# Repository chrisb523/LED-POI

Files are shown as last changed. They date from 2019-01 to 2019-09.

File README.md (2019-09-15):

# LED POI Project
This is a project that converts JPEG format images to code usable on LED poi with arduino-based operating systems. Additionally, it contains the documentation necessescary to build poi, in addition to the materials I used to build them myself. Furthermore, it outlines some of the difficulties I had along the way developing both the software and hardware components, and the solutions I found. The project is still in development, but most features are reliable and tested. I would encourage modification of the original programs and hardware to any specifications.   

# Running and Compiling the Program:

First begin by placing the desired image, which must be in the JPEG format (.jpg) into the arduino program directory (/makerpoi_code/)

Then, ensure that the number of pixels is correctly defined in convert.py (only nessescary if you change the number of LEDs)
Before running the program, see the software section, and ensure you have all of the dependencies

Execute the run.bat file in the program directory, or use a shell to execute the convert.py program

Examine the arduino code file, and ensure that are variables are set correctly to the specifications of the project 
  -Make sure the Pinout is correct
  -Make sure the voltages in the battery measuring function are correct (depending on whether you are using 3.3v or 5v logic)
  
# Software: 
The project is based off of python 3.7 and C++ (Which is used by arduino IDE). The download link to python 3.7 is (https://www.python.org/downloads/release/python-373/) and the download link to arduino IDE is (https://www.arduino.cc/en/main/software). For the python install, remember to set environment variables. In addition to python, one must also install or upgrade pip, which can be done from the command line using: 

py -m pip upgrade pip

Then, install all dependencies for the convert image program (cv2, PIL, and numpy). However, PIL has been deprecated, and PILLOW is in use with more recent versions of python. To install it, use:

 py -m pip install pillow
 
This should meet all of the basic installation requirements for the project. However, there are some aspects of the ardino IDE that may need to be tweaked. The SAMD boards for arduino have to be installed, in addition to the Neopixel library. With this, all of the software should be configured correctly.

Then, install the Trinket m0 board using this link: https://adafruit.github.io/arduino-board-index/package_adafruit_index.json

 # Hardware: 
The project requires a number of hardware components, most of which are . All of the hardware can be purchased from Adafruit's website or Amazon. For the project, I used the following parts: 

ALITOVE 3.2ft 144 Pixels WS2812B Individually Addressable LED Strip Light (https://www.amazon.com/gp/product/B019DYZNO6/ref=ppx_yo_dt_b_asin_title_o07_s00?ie=UTF8&psc=1)

2 of Adafruit Trinket M0 - for use with CircuitPython & Arduino IDE (https://www.amazon.com/gp/product/B01MR2S7K0/ref=ppx_yo_dt_b_asin_title_o00_s00?ie=UTF8&psc=1)

Breadboard and generic wires (Avaliable from numerous electronic stores)

Micro-USB cable (https://www.amazon.com/AmazonBasics-Male-Micro-Cable-Black/dp/B072J1BSV6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)

2 of uxcell Power Supply DC 3.7V 500mAh Li-po batteries (https://www.amazon.com/gp/product/B0767D8GVG/ref=ppx_yo_dt_b_asin_title_o00_s00?ie=UTF8&psc=1)

2 of Adafruit LiIon/LiPoly Backpack Add-On for Pro Trinket/ItsyBitsy (https://www.adafruit.com/product/2124)

Generic Nylon Rope

In total, the project cost me around $66.00, as I had a breadboard, wires, nylon cord, and cables. 
-------------------------------------------------------------------------------------------------------
Additional Items:
If you so wish to build the cases for the POI, it will cost extra, but I found that it was important to build them to protect from water damage and collisions. 

4 Vinyl Caps
(https://www.amazon.com/gp/product/B0747RVMRZ/ref=ppx_yo_dt_b_asin_title_o04_s00?ie=UTF8&psc=1)

Clear Polycarbonate Tubing, 1-1/8" ID, 1-1/4" OD, 1/16" Wall, 3' Length
(https://www.amazon.com/gp/product/B000OMFLD0/ref=ppx_yo_dt_b_asin_title_o05_s00?ie=UTF8&psc=1)

Tissue Paper or Towels - To act as a shock absorber and spacer

# Assembly

The initial development board appeared as so, with some soldering required for the test board:

# Software Development

The software development began with the convert.py script developed in python. It converts the image to an rgb array, and prints it out in the format of a header file. This process was not easy, and the file was cleaned by multiple replace functions. It can be run with the run.bat file. 

Initially, I had written the python script to export a header file that contained all of the rgb values in arrays. However, I later decided to make the python script handle the placements of these values directly into the files. This reduced the time taken by the trinket board to process the images, and allowed for a clearer image with higher resolution. 

With the second version of the project, I added a battery detector to tell the user whether or not the battery is running low, using the colors red and green. This was enabled by the soldering of the usb pin to an analog read pin, and a software analog read function that detetected the voltage on startup. Futhermore, this feature also has the ability to prevent the POI from displaying the image at all if the POI are charging or plugged into a computer for code upload. Instead, the POI will flash blue one time. This works due to the property that the USB pin outputs differing voltages based on factors such as battery level, and whether or not the POI are charging.

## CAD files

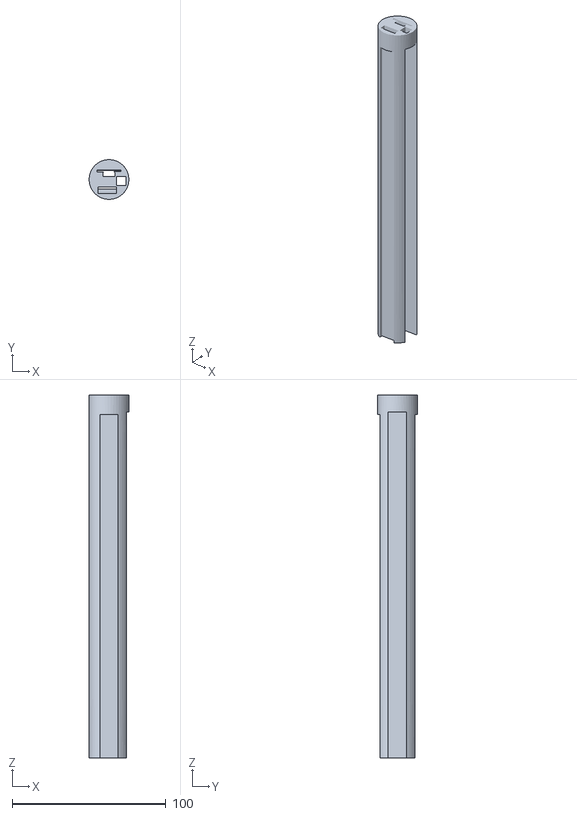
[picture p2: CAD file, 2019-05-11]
poiinsert.stl
25.9 x 25.8 x 236.2

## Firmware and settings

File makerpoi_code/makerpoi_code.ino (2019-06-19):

#define VBATPIN 2
#include <Adafruit_NeoPixel.h>
#define PIN 1
#define NUM_LEDS 32
#define Button 3
Adafruit_NeoPixel strip = Adafruit_NeoPixel(32, PIN, NEO_GRB + NEO_KHZ800);
float measuredvbat;
int buttonState = 0;
int img = 1;
int numimg = 2;
void setup() {
  strip.begin();
  strip.setBrightness(40);
  measuredvbat = bat();
  for (int i = 0; i < 32; i++) {
    if (measuredvbat > 1.5 && measuredvbat < 2)
      strip.setPixelColor(i, 0, 255, 0);
    if (measuredvbat > 3.29 && measuredvbat < 3.31)
      strip.setPixelColor(i, 0, 0, 255);
    if (measuredvbat < 1.5)
      strip.setPixelColor(i, 255, 0, 0);
  }
  strip.show();
  delay(500);
  strip.clear();
  strip.show();
  pinMode(Button, INPUT);
}
float bat() {
  float measuredvbat = analogRead(VBATPIN);
  return measuredvbat * 3.30 / 1023;
}
void loop() {
  while (measuredvbat > 3.29) {
    delay(1);
  }
  buttonState = digitalRead(Button);
  if (buttonState == HIGH) {
    img++;
    delay(32);
  }
  if (img > numimg)
    img = 1;

  if (img == 1)
    image0();
  if (img == 2)
    image1();
}
void image0() {
  strip.setPixelColor(0, 0, 125, 100);
  strip.setPixelColor(1, 57, 175, 163);
  strip.setPixelColor(2, 108, 209, 221);
  strip.setPixelColor(3, 128, 206, 245);
  strip.setPixelColor(4, 134, 198, 255);
  strip.setPixelColor(5, 129, 201, 255);
  strip.setPixelColor(6, 102, 210, 255);
  strip.setPixelColor(7, 67, 220, 255);
  strip.setPixelColor(8, 40, 222, 236);
  strip.setPixelColor(9, 21, 185, 187);
  strip.setPixelColor(10, 0, 99, 102);
  strip.setPixelColor(11, 0, 12, 22);
  strip.setPixelColor(12, 6, 0, 9);
  strip.setPixelColor(13, 12, 3, 8);
  strip.setPixelColor(14, 0, 18, 7);
  strip.setPixelColor(15, 0, 20, 0);
  strip.setPixelColor(16, 22, 0, 0);
  strip.setPixelColor(17, 7, 0, 18);
  strip.setPixelColor(18, 0, 1, 28);
  strip.setPixelColor(19, 0, 10, 0);
  strip.setPixelColor(20, 10, 1, 0);
  strip.setPixelColor(21, 75, 14, 29);
  strip.setPixelColor(22, 203, 89, 140);
  strip.setPixelColor(23, 255, 146, 124);
  strip.setPixelColor(24, 255, 184, 15);
  strip.setPixelColor(25, 255, 201, 0);
  strip.setPixelColor(26, 237, 213, 0);
  strip.setPixelColor(27, 219, 215, 2);
  strip.setPixelColor(28, 229, 219, 36);
  strip.setPixelColor(29, 251, 205, 67);
  strip.setPixelColor(30, 239, 142, 100);
  strip.setPixelColor(31, 255, 121, 176);
  strip.show();
  delay(1);
  strip.setPixelColor(0, 0, 49, 34);
  strip.setPixelColor(1, 15, 107, 102);
  strip.setPixelColor(2, 76, 169, 177);
  strip.setPixelColor(3, 109, 200, 229);
  strip.setPixelColor(4, 115, 206, 251);
  strip.setPixelColor(5, 106, 201, 255);
  strip.setPixelColor(6, 97, 206, 255);
  strip.setPixelColor(7, 96, 223, 255);
  strip.setPixelColor(8, 81, 221, 248);
  strip.setPixelColor(9, 73, 205, 218);
  strip.setPixelColor(10, 51, 156, 160);
  strip.setPixelColor(11, 14, 84, 86);
  strip.setPixelColor(12, 0, 22, 23);
  strip.setPixelColor(13, 0, 6, 5);
  strip.setPixelColor(14, 0, 6, 0);
  strip.setPixelColor(15, 0, 16, 6);
  strip.setPixelColor(16, 17, 0, 2);
  strip.setPixelColor(17, 19, 8, 6);
  strip.setPixelColor(18, 2, 4, 3);
  strip.setPixelColor(19, 5, 0, 16);
  strip.setPixelColor(20, 37, 2, 24);
  strip.setPixelColor(21, 175, 106, 90);
  strip.setPixelColor(22, 255, 169, 90);
  strip.setPixelColor(23, 255, 174, 51);
  strip.setPixelColor(24, 255, 194, 42);
  strip.setPixelColor(25, 255, 198, 6);
  strip.setPixelColor(26, 240, 203, 0);
  strip.setPixelColor(27, 248, 212, 0);
  strip.setPixelColor(28, 253, 205, 35);
  strip.setPixelColor(29, 234, 166, 93);
  strip.setPixelColor(30, 224, 146, 142);
  strip.setPixelColor(31, 98, 18, 43);
  strip.show();
  delay(1);
  strip.setPixelColor(0, 0, 13, 11);
  strip.setPixelColor(1, 0, 34, 33);
  strip.setPixelColor(2, 20, 97, 103);
  strip.setPixelColor(3, 64, 166, 180);
  strip.setPixelColor(4, 91, 210, 232);
  strip.setPixelColor(5, 91, 214, 247);
  strip.setPixelColor(6, 96, 207, 250);
  strip.setPixelColor(7, 114, 209, 255);
  strip.setPixelColor(8, 124, 208, 252);
  strip.setPixelColor(9, 122, 211, 241);
  strip.setPixelColor(10, 101, 205, 216);
  strip.setPixelColor(11, 54, 167, 163);
  strip.setPixelColor(12, 0, 94, 82);
  strip.setPixelColor(13, 0, 24, 16);
  strip.setPixelColor(14, 0, 5, 5);
  strip.setPixelColor(15, 17, 0, 8);
  strip.setPixelColor(16, 11, 0, 21);
  strip.setPixelColor(17, 8, 0, 0);
  strip.setPixelColor(18, 10, 0, 0);
  strip.setPixelColor(19, 37, 2, 32);
  strip.setPixelColor(20, 185, 121, 156);
  strip.setPixelColor(21, 245, 172, 104);
  strip.setPixelColor(22, 255, 202, 12);
  strip.setPixelColor(23, 255, 205, 0);
  strip.setPixelColor(24, 251, 201, 28);
  strip.setPixelColor(25, 245, 190, 35);
  strip.setPixelColor(26, 255, 202, 6);
  strip.setPixelColor(27, 255, 195, 0);
  strip.setPixelColor(28, 251, 155, 42);
  strip.setPixelColor(29, 231, 146, 141);
  strip.setPixelColor(30, 76, 32, 57);
  strip.setPixelColor(31, 4, 0, 0);
  strip.show();
  delay(1);
  strip.setPixelColor(0, 0, 2, 5);
  strip.setPixelColor(1, 0, 6, 11);
  strip.setPixelColor(2, 0, 27, 30);
  strip.setPixelColor(3, 9, 99, 100);
  strip.setPixelColor(4, 58, 182, 184);
  strip.setPixelColor(5, 86, 220, 229);
  strip.setPixelColor(6, 98, 214, 239);
  strip.setPixelColor(7, 118, 197, 238);
  strip.setPixelColor(8, 140, 193, 243);
  strip.setPixelColor(9, 136, 198, 239);
  strip.setPixelColor(10, 114, 210, 232);
  strip.setPixelColor(11, 78, 212, 211);
  strip.setPixelColor(12, 36, 172, 158);
  strip.setPixelColor(13, 4, 97, 87);
  strip.setPixelColor(14, 0, 21, 26);
  strip.setPixelColor(15, 15, 0, 9);
  strip.setPixelColor(16, 1, 0, 26);
  strip.setPixelColor(17, 11, 0, 8);
  strip.setPixelColor(18, 46, 15, 10);
  strip.setPixelColor(19, 180, 124, 107);
  strip.setPixelColor(20, 240, 168, 118);
  strip.setPixelColor(21, 255, 198, 81);
  strip.setPixelColor(22, 232, 182, 0);
  strip.setPixelColor(23, 249, 216, 0);
  strip.setPixelColor(24, 237, 204, 0);
  strip.setPixelColor(25, 255, 202, 1);
  strip.setPixelColor(26, 255, 193, 41);
  strip.setPixelColor(27, 255, 155, 67);
  strip.setPixelColor(28, 241, 130, 110);
  strip.setPixelColor(29, 88, 15, 34);
  strip.setPixelColor(30, 17, 3, 20);
  strip.setPixelColor(31, 0, 12, 8);
  strip.show();
  delay(1);
  strip.setPixelColor(0, 16, 11, 17);
  strip.setPixelColor(1, 0, 0, 5);
  strip.setPixelColor(2, 0, 7, 9);
  strip.setPixelColor(3, 0, 32, 29);
  strip.setPixelColor(4, 13, 108, 100);
  strip.setPixelColor(5, 57, 176, 172);
  strip.setPixelColor(6, 93, 208, 215);
  strip.setPixelColor(7, 121, 211, 237);
  strip.setPixelColor(8, 131, 198, 240);
  strip.setPixelColor(9, 129, 196, 239);
  strip.setPixelColor(10, 113, 203, 237);
  strip.setPixelColor(11, 93, 215, 230);
  strip.setPixelColor(12, 85, 215, 217);
  strip.setPixelColor(13, 68, 171, 170);
  strip.setPixelColor(14, 32, 82, 91);
  strip.setPixelColor(15, 0, 6, 22);
  strip.setPixelColor(16, 0, 16, 24);
  strip.setPixelColor(17, 1, 0, 28);
  strip.setPixelColor(18, 157, 106, 123);
  strip.setPixelColor(19, 252, 182, 113);
  strip.setPixelColor(20, 255, 190, 41);
  strip.setPixelColor(21, 221, 169, 5);
  strip.setPixelColor(22, 255, 221, 58);
  strip.setPixelColor(23, 238, 200, 0);
  strip.setPixelColor(24, 255, 213, 0);
  strip.setPixelColor(25, 255, 202, 0);
  strip.setPixelColor(26, 255, 156, 58);
  strip.setPixelColor(27, 238, 137, 151);
  strip.setPixelColor(28, 89, 18, 52);
  strip.setPixelColor(29, 21, 0, 0);
  strip.setPixelColor(30, 2, 1, 0);
  strip.setPixelColor(31, 3, 10, 38);
  strip.show();
  delay(1);
  strip.setPixelColor(0, 0, 0, 2);
  strip.setPixelColor(1, 5, 3, 4);
  strip.setPixelColor(2, 0, 0, 2);
  strip.setPixelColor(3, 0, 5, 4);
  strip.setPixelColor(4, 0, 28, 23);
  strip.setPixelColor(5, 14, 91, 83);
  strip.setPixelColor(6, 62, 165, 162);
  strip.setPixelColor(7, 108, 219, 228);
  strip.setPixelColor(8, 106, 212, 236);
  strip.setPixelColor(9, 116, 214, 251);
  strip.setPixelColor(10, 115, 208, 249);
  strip.setPixelColor(11, 110, 204, 240);
  strip.setPixelColor(12, 119, 213, 241);
  strip.setPixelColor(13, 115, 206, 225);
  strip.setPixelColor(14, 69, 153, 164);
  strip.setPixelColor(15, 13, 90, 98);
  strip.setPixelColor(16, 0, 25, 21);
  strip.setPixelColor(17, 0, 1, 25);
  strip.setPixelColor(18, 85, 36, 42);
  strip.setPixelColor(19, 240, 164, 86);
  strip.setPixelColor(20, 255, 201, 35);
  strip.setPixelColor(21, 255, 219, 27);
  strip.setPixelColor(22, 231, 200, 22);
  strip.setPixelColor(23, 255, 206, 29);
  strip.setPixelColor(24, 255, 205, 25);
  strip.setPixelColor(25, 255, 155, 19);
  strip.setPixelColor(26, 232, 141, 97);
  strip.setPixelColor(27, 75, 26, 47);
  strip.setPixelColor(28, 4, 0, 14);
  strip.setPixelColor(29, 0, 9, 0);
  strip.setPixelColor(30, 9, 0, 7);
  strip.setPixelColor(31, 22, 0, 34);
  strip.show();
  delay(1);
  strip.setPixelColor(0, 0, 2, 2);
  strip.setPixelColor(1, 1, 1, 1);
  strip.setPixelColor(2, 10, 2, 0);
  strip.setPixelColor(3, 8, 0, 0);
  strip.setPixelColor(4, 0, 0, 0);
  strip.setPixelColor(5, 0, 20, 15);
  strip.setPixelColor(6, 18, 93, 88);
  strip.setPixelColor(7, 50, 169, 167);
  strip.setPixelColor(8, 70, 211, 220);
  strip.setPixelColor(9, 88, 222, 247);
  strip.setPixelColor(10, 108, 215, 255);
  strip.setPixelColor(11, 122, 198, 250);
  strip.setPixelColor(12, 133, 196, 247);
  strip.setPixelColor(13, 129, 207, 245);
  strip.setPixelColor(14, 89, 199, 216);
  strip.setPixelColor(15, 44, 178, 181);
  strip.setPixelColor(16, 0, 90, 96);
  strip.setPixelColor(17, 0, 26, 11);
  strip.setPixelColor(18, 15, 0, 0);
  strip.setPixelColor(19, 100, 40, 0);
  strip.setPixelColor(20, 242, 180, 67);
  strip.setPixelColor(21, 247, 207, 31);
  strip.setPixelColor(22, 234, 199, 0);
  strip.setPixelColor(23, 255, 196, 45);
  strip.setPixelColor(24, 242, 141, 85);
  strip.setPixelColor(25, 232, 127, 131);
  strip.setPixelColor(26, 81, 20, 15);
  strip.setPixelColor(27, 4, 10, 0);
  strip.setPixelColor(28, 0, 17, 0);
  strip.setPixelColor(29, 0, 12, 13);
  strip.setPixelColor(30, 18, 0, 26);
  strip.setPixelColor(31, 41, 0, 18);
  strip.show();
  delay(1);
  strip.setPixelColor(0, 6, 5, 10);
  strip.setPixelColor(1, 0, 0, 0);
  strip.setPixelColor(2, 4, 0, 0);
  strip.setPixelColor(3, 16, 2, 0);
  strip.setPixelColor(4, 14, 0, 0);
  strip.setPixelColor(5, 1, 0, 0);
  strip.setPixelColor(6, 0, 30, 30);
  strip.setPixelColor(7, 0, 95, 94);
  strip.setPixelColor(8, 50, 194, 195);
  strip.setPixelColor(9, 59, 215, 230);
  strip.setPixelColor(10, 89, 217, 252);
  strip.setPixelColor(11, 114, 199, 254);
  strip.setPixelColor(12, 129, 191, 252);
  strip.setPixelColor(13, 124, 200, 249);
  strip.setPixelColor(14, 98, 213, 242);
  strip.setPixelColor(15, 68, 218, 232);
  strip.setPixelColor(16, 55, 170, 201);
  strip.setPixelColor(17, 18, 104, 77);
  strip.setPixelColor(18, 0, 27, 0);
  strip.setPixelColor(19, 20, 3, 0);
  strip.setPixelColor(20, 82, 32, 0);
  strip.setPixelColor(21, 221, 164, 48);
  strip.setPixelColor(22, 255, 220, 77);
  strip.setPixelColor(23, 235, 167, 82);
  strip.setPixelColor(24, 211, 132, 151);
  strip.setPixelColor(25, 81, 18, 73);
  strip.setPixelColor(26, 15, 0, 0);
  strip.setPixelColor(27, 0, 13, 0);
  strip.setPixelColor(28, 0, 16, 0);
  strip.setPixelColor(29, 0, 0, 19);
  strip.setPixelColor(30, 13, 0, 18);
  strip.setPixelColor(31, 37, 0, 0);
  strip.show();
  delay(1);
  strip.setPixelColor(0, 7, 0, 5);
  strip.setPixelColor(1, 4, 2, 5);
  strip.setPixelColor(2, 5, 7, 4);
  strip.setPixelColor(3, 3, 0, 0);
  strip.setPixelColor(4, 11, 0, 0);
  strip.setPixelColor(5, 11, 0, 0);
  strip.setPixelColor(6, 0, 4, 10);
  strip.setPixelColor(7, 0, 17, 21);
  strip.setPixelColor(8, 0, 98, 102);
  strip.setPixelColor(9, 44, 188, 199);
  strip.setPixelColor(10, 73, 217, 241);
  strip.setPixelColor(11, 97, 215, 255);
  strip.setPixelColor(12, 116, 210, 255);
  strip.setPixelColor(13, 100, 192, 243);
  strip.setPixelColor(14, 107, 216, 255);
  strip.setPixelColor(15, 91, 215, 249);
  strip.setPixelColor(16, 90, 202, 248);
  strip.setPixelColor(17, 58, 168, 167);
  strip.setPixelColor(18, 15, 104, 48);
  strip.setPixelColor(19, 0, 32, 0);
  strip.setPixelColor(20, 18, 4, 0);
  strip.setPixelColor(21, 108, 43, 1);
  strip.setPixelColor(22, 216, 133, 119);
  strip.setPixelColor(23, 206, 139, 146);
  strip.setPixelColor(24, 50, 20, 32);
  strip.setPixelColor(25, 7, 10, 15);
  strip.setPixelColor(26, 0, 5, 5);
  strip.setPixelColor(27, 3, 4, 9);
  strip.setPixelColor(28, 9, 0, 12);
  strip.setPixelColor(29, 11, 0, 9);
  strip.setPixelColor(30, 8, 0, 0);
  strip.setPixelColor(31, 4, 8, 0);
  strip.show();
  delay(1);
  strip.setPixelColor(0, 7, 0, 5);
  strip.setPixelColor(1, 1, 0, 4);
  strip.setPixelColor(2, 0, 1, 0);
  strip.setPixelColor(3, 0, 4, 0);
  strip.setPixelColor(4, 8, 3, 0);
  strip.setPixelColor(5, 16, 1, 4);
  strip.setPixelColor(6, 13, 3, 12);
  strip.setPixelColor(7, 0, 10, 19);
  strip.setPixelColor(8, 0, 26, 35);
  strip.setPixelColor(9, 0, 91, 98);
  strip.setPixelColor(10, 23, 161, 172);
  strip.setPixelColor(11, 73, 218, 237);
  strip.setPixelColor(12, 83, 216, 247);
  strip.setPixelColor(13, 113, 226, 255);
  strip.setPixelColor(14, 106, 202, 253);
  strip.setPixelColor(15, 112, 197, 252);
  strip.setPixelColor(16, 110, 209, 248);
  strip.setPixelColor(17, 93, 207, 241);
  strip.setPixelColor(18, 48, 172, 170);
  strip.setPixelColor(19, 9, 112, 59);
  strip.setPixelColor(20, 0, 29, 0);
  strip.setPixelColor(21, 25, 0, 0);
  strip.setPixelColor(22, 80, 6, 69);
  strip.setPixelColor(23, 75, 27, 75);
  strip.setPixelColor(24, 7, 15, 2);
  strip.setPixelColor(25, 0, 17, 0);
  strip.setPixelColor(26, 0, 7, 14);
  strip.setPixelColor(27, 8, 0, 43);
  strip.setPixelColor(28, 30, 0, 26);
  strip.setPixelColor(29, 26, 0, 0);
  strip.setPixelColor(30, 0, 8, 0);
  strip.setPixelColor(31, 0, 16, 0);
  strip.show();
  delay(1);
  strip.setPixelColor(0, 2, 5, 10);
  strip.setPixelColor(1, 0, 0, 4);
  strip.setPixelColor(2, 1, 0, 4);
  strip.setPixelColor(3, 3, 0, 2);
  strip.setPixelColor(4, 4, 0, 2);
  strip.setPixelColor(5, 6, 0, 2);
  strip.setPixelColor(6, 6, 0, 4);
  strip.setPixelColor(7, 2, 1, 9);
  strip.setPixelColor(8, 0, 9, 15);
  strip.setPixelColor(9, 0, 18, 19);
  strip.setPixelColor(10, 9, 118, 115);
  strip.setPixelColor(11, 21, 165, 165);
  strip.setPixelColor(12, 72, 223, 234);
  strip.setPixelColor(13, 98, 223, 255);
  strip.setPixelColor(14, 119, 204, 255);
  strip.setPixelColor(15, 129, 186, 255);
  strip.setPixelColor(16, 117, 196, 227);
  strip.setPixelColor(17, 107, 213, 255);
  strip.setPixelColor(18, 67, 203, 251);
  strip.setPixelColor(19, 38, 174, 196);
  strip.setPixelColor(20, 6, 100, 102);
  strip.setPixelColor(21, 0, 9, 21);
  strip.setPixelColor(22, 8, 0, 21);
  strip.setPixelColor(23, 16, 0, 20);
  strip.setPixelColor(24, 0, 7, 3);
  strip.setPixelColor(25, 0, 9, 4);
  strip.setPixelColor(26, 0, 2, 25);
  strip.setPixelColor(27, 8, 0, 32);
  strip.setPixelColor(28, 24, 0, 11);
  strip.setPixelColor(29, 20, 0, 0);
  strip.setPixelColor(30, 0, 9, 0);
  strip.setPixelColor(31, 0, 14, 5);
  strip.show();
  delay(1);
  strip.setPixelColor(0, 0, 11, 2);
  strip.setPixelColor(1, 0, 6, 5);
  strip.setPixelColor(2, 10, 0, 7);
  strip.setPixelColor(3, 14, 0, 7);
  strip.setPixelColor(4, 10, 0, 7);
  strip.setPixelColor(5, 1, 0, 5);
  strip.setPixelColor(6, 0, 1, 0);
  strip.setPixelColor(7, 8, 4, 1);
  strip.setPixelColor(8, 6, 1, 0);
  strip.setPixelColor(9, 0, 6, 0);
  strip.setPixelColor(10, 0, 34, 19);
  strip.setPixelColor(11, 11, 118, 102);
  strip.setPixelColor(12, 27, 158, 153);
  strip.setPixelColor(13, 100, 221, 240);
  strip.setPixelColor(14, 106, 192, 239);
  strip.setPixelColor(15, 139, 196, 255);
  strip.setPixelColor(16, 140, 201, 246);
  strip.setPixelColor(17, 118, 210, 255);
  strip.setPixelColor(18, 78, 208, 255);
  strip.setPixelColor(19, 62, 213, 255);
  strip.setPixelColor(20, 38, 174, 232);
  strip.setPixelColor(21, 0, 95, 110);
  strip.setPixelColor(22, 0, 39, 14);
  strip.setPixelColor(23, 0, 8, 0);
  strip.setPixelColor(24, 6, 3, 14);
  strip.setPixelColor(25, 7, 0, 32);
  strip.setPixelColor(26, 4, 0, 25);
  strip.setPixelColor(27, 0, 1, 6);
  strip.setPixelColor(28, 0, 1, 0);
  strip.setPixelColor(29, 0, 0, 5);
  strip.setPixelColor(30, 0, 6, 11);
  strip.setPixelColor(31, 0, 5, 2);
  strip.show();
  delay(1);
  strip.setPixelColor(0, 0, 12, 0);
  strip.setPixelColor(1, 0, 9, 3);
  strip.setPixelColor(2, 14, 0, 8);
  strip.setPixelColor(3, 18, 0, 9);
  strip.setPixelColor(4, 17, 0, 17);
  strip.setPixelColor(5, 10, 9, 17);
  strip.setPixelColor(6, 3, 8, 2);
  strip.setPixelColor(7, 9, 3, 0);
  strip.setPixelColor(8, 17, 0, 0);
  strip.setPixelColor(9, 23, 2, 0);
  strip.setPixelColor(10, 0, 5, 0);
  strip.setPixelColor(11, 0, 17, 0);
  strip.setPixelColor(12, 28, 112, 97);
  strip.setPixelColor(13, 48, 146, 155);
  strip.setPixelColor(14, 108, 201, 235);
  strip.setPixelColor(15, 122, 203, 255);
  strip.setPixelColor(16, 138, 198, 255);
  strip.setPixelColor(17, 115, 198, 252);
  strip.setPixelColor(18, 91, 207, 255);
  strip.setPixelColor(19, 88, 232, 255);
  strip.setPixelColor(20, 63, 222, 255);
  strip.setPixelColor(21, 28, 177, 199);
  strip.setPixelColor(22, 1, 110, 91);
  strip.setPixelColor(23, 0, 18, 0);
  strip.setPixelColor(24, 1, 0, 2);
  strip.setPixelColor(25, 15, 0, 7);
  strip.setPixelColor(26, 10, 0, 3);
  strip.setPixelColor(27, 0, 7, 2);
  strip.setPixelColor(28, 0, 8, 16);
  strip.setPixelColor(29, 0, 4, 27);
  strip.setPixelColor(30, 0, 2, 14);
  strip.setPixelColor(31, 8, 0, 0);
  strip.show();
  delay(1);
  strip.setPixelColor(0, 0, 7, 0);
  strip.setPixelColor(1, 2, 8, 0);
  strip.setPixelColor(2, 4, 0, 4);
  strip.setPixelColor(3, 7, 0, 11);
  strip.setPixelColor(4, 12, 3, 22);
  strip.setPixelColor(5, 8, 5, 14);
  strip.setPixelColor(6, 4, 0, 0);
  strip.setPixelColor(7, 15, 0, 0);
  strip.setPixelColor(8, 79, 44, 6);
  strip.setPixelColor(9, 131, 84, 40);
  strip.setPixelColor(10, 40, 2, 0);
  strip.setPixelColor(11, 11, 1, 0);
  strip.setPixelColor(12, 0, 12, 0);
  strip.setPixelColor(13, 20, 88, 89);
  strip.setPixelColor(14, 58, 154, 176);
  strip.setPixelColor(15, 96, 206, 239);
  strip.setPixelColor(16, 114, 192, 255);
  strip.setPixelColor(17, 112, 197, 252);
  strip.setPixelColor(18, 106, 204, 239);
  strip.setPixelColor(19, 99, 223, 247);
  strip.setPixelColor(20, 78, 227, 251);
  strip.setPixelColor(21, 65, 219, 245);
  strip.setPixelColor(22, 51, 184, 203);
  strip.setPixelColor(23, 16, 100, 102);
  strip.setPixelColor(24, 0, 18, 2);
  strip.setPixelColor(25, 4, 2, 0);
  strip.setPixelColor(26, 6, 0, 0);
  strip.setPixelColor(27, 0, 3, 10);
  strip.setPixelColor(28, 0, 6, 28);
  strip.setPixelColor(29, 0, 4, 25);
  strip.setPixelColor(30, 0, 1, 5);
  strip.setPixelColor(31, 7, 0, 0);
  strip.show();
  delay(1);
  strip.setPixelColor(0, 17, 0, 0);
  strip.setPixelColor(1, 10, 3, 0);
  strip.setPixelColor(2, 0, 3, 2);
  strip.setPixelColor(3, 0, 4, 12);
  strip.setPixelColor(4, 0, 2, 16);
  strip.setPixelColor(5, 1, 0, 7);
  strip.setPixelColor(6, 22, 0, 0);
  strip.setPixelColor(7, 75, 35, 9);
  strip.setPixelColor(8, 192, 138, 91);
  strip.setPixelColor(9, 222, 158, 97);
  strip.setPixelColor(10, 177, 113, 52);
  strip.setPixelColor(11, 62, 11, 0);
  strip.setPixelColor(12, 13, 0, 0);
  strip.setPixelColor(13, 0, 15, 11);
  strip.setPixelColor(14, 1, 99, 110);
  strip.setPixelColor(15, 26, 161, 180);
  strip.setPixelColor(16, 88, 197, 240);
  strip.setPixelColor(17, 119, 216, 255);
  strip.setPixelColor(18, 122, 208, 241);
  strip.setPixelColor(19, 111, 204, 219);
  strip.setPixelColor(20, 98, 211, 219);
  strip.setPixelColor(21, 87, 221, 233);
  strip.setPixelColor(22, 77, 216, 237);
  strip.setPixelColor(23, 58, 179, 190);
  strip.setPixelColor(24, 12, 93, 84);
  strip.setPixelColor(25, 2, 41, 22);
  strip.setPixelColor(26, 0, 3, 0);
  strip.setPixelColor(27, 6, 0, 0);
  strip.setPixelColor(28, 6, 1, 5);
  strip.setPixelColor(29, 0, 2, 1);
  strip.setPixelColor(30, 0, 4, 4);
  strip.setPixelColor(31, 0, 3, 11);
  strip.show();
  delay(1);
  strip.setPixelColor(0, 32, 0, 0);
  strip.setPixelColor(1, 11, 0, 0);
  strip.setPixelColor(2, 0, 9, 1);
  strip.setPixelColor(3, 0, 21, 20);
  strip.setPixelColor(4, 0, 10, 18);
  strip.setPixelColor(5, 1, 0, 7);
  strip.setPixelColor(6, 81, 43, 42);
  strip.setPixelColor(7, 194, 136, 112);
  strip.setPixelColor(8, 235, 168, 116);
  strip.setPixelColor(9, 255, 194, 125);
  strip.setPixelColor(10, 255, 190, 122);
  strip.setPixelColor(11, 161, 91, 39);
  strip.setPixelColor(12, 36, 1, 0);
  strip.setPixelColor(13, 0, 9, 0);
  strip.setPixelColor(14, 0, 36, 42);
  strip.setPixelColor(15, 0, 106, 116);
  strip.setPixelColor(16, 33, 163, 176);
  strip.setPixelColor(17, 97, 207, 232);
  strip.setPixelColor(18, 116, 198, 235);
  strip.setPixelColor(19, 123, 192, 225);
  strip.setPixelColor(20, 130, 212, 226);
  strip.setPixelColor(21, 109, 219, 216);
  strip.setPixelColor(22, 83, 223, 214);
  strip.setPixelColor(23, 72, 216, 217);
  strip.setPixelColor(24, 57, 175, 189);
  strip.setPixelColor(25, 22, 89, 106);
  strip.setPixelColor(26, 1, 15, 18);
  strip.setPixelColor(27, 18, 0, 0);
  strip.setPixelColor(28, 26, 0, 0);
  strip.setPixelColor(29, 11, 0, 0);
  strip.setPixelColor(30, 0, 4, 9);
  strip.setPixelColor(31, 0, 7, 35);
  strip.show();
  delay(1);
  strip.setPixelColor(0, 24, 11, 0);
  strip.setPixelColor(1, 18, 0, 0);
  strip.setPixelColor(2, 13, 0, 8);
  strip.setPixelColor(3, 0, 7, 0);
  strip.setPixelColor(4, 0, 5, 0);
  strip.setPixelColor(5, 83, 32, 41);
  strip.setPixelColor(6, 228, 101, 131);
  strip.setPixelColor(7, 255, 144, 129);
  strip.setPixelColor(8, 255, 171, 57);
  strip.setPixelColor(9, 255, 199, 10);
  strip.setPixelColor(10, 245, 203, 0);
  strip.setPixelColor(11, 242, 223, 23);
  strip.setPixelColor(12, 133, 145, 0);
  strip.setPixelColor(13, 18, 33, 0);
  strip.setPixelColor(14, 28, 0, 0);
  strip.setPixelColor(15, 59, 0, 6);
  strip.setPixelColor(16, 9, 91, 87);
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

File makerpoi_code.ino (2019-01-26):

#include <Adafruit_NeoPixel.h>
#include "imagez.h"
#define PIN 1

// Parameter 1 = number of pixels in strip
// Parameter 2 = Trinket m0 pin number (Only pin 1 is valid for PMW)
// Parameter 3 = pixel type flags, add together as needed:
//   NEO_KHZ800  800 KHz bitstream (most NeoPixel products w/WS2812 LEDs)
//   NEO_KHZ400  400 KHz (classic 'v1' (not v2) FLORA pixels, WS2811 drivers)
//   NEO_GRB     Pixels are wired for GRB bitstream (most NeoPixel products)
//   NEO_RGB     Pixels are wired for RGB bitstream (v1 FLORA pixels, not v2)
Adafruit_NeoPixel strip = Adafruit_NeoPixel(144, PIN, NEO_GRB + NEO_KHZ800);

// IMPORTANT: To reduce NeoPixel burnout risk, add 1000 uF capacitor across
// pixel power leads, add 300 - 500 Ohm resistor on first pixel's data input
// and minimize distance between Arduino and first pixel. Avoid connecting
// on a live circuit... if you must, connect GND first.

void setup() {
  strip.begin();
  strip.setBrightness(50);
  strip.show(); // initialize all pixels to "off"
}

void imageinit() {
  //File file=new File("graphics.h");
  
  //int rgbArray = file.read().split('\n');
  //int size = len(rgbArray); **/
}

void loop() {
  for i in range(0, size):
    i=i+1;
    //strip.setPixelColor(rgbArray[i]);
}

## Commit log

2019-01-28 convert.py updated
    Finished correct formatting for header file
    [makerpoi_code.ino]
2019-04-07 v0.8.1 Converter is wide-image ready
    Convert.py fixed and runner batch file created
    [makerpoi_code.ino]
2019-04-13 v0.8.2 Software now allows for larger images with multiple pixels in width
    Additionally, coloration fixes completed.
    [makerpoi_code.ino]
2019-05-11 v1.0 Optimized the LED algorithm and added the 3d print model
    Removed all for loops in makerpoi_code.ino and added the 3D model of the poi insert. Additionally, added some test images from themoodhoops packages.
    [poiinsert.stl]
2019-05-21 temp: voltage measurement and display
2019-05-22 Revert "tempv2"
    This reverts commit 625916685c719821c5d97f2d517183820a13fabd.
    [makerpoi_code.ino]
2019-05-22 v1.1 Battery Level Indicator, and Charging Detector
    Battery level indicator doesn't yet match voltages, but the base code has been added. Additionally, the POI will now stop displaying patterns when charging, and will appear blue on startup.
2019-05-22 bug fixes for convert.py
    [makerpoi_code.ino]
2019-06-01 v1.2 Battery Voltage Indicator Fixed
    Correct voltages are now used for indicating weather the battery is low or charged.
2019-06-17 v2.0 New Battery Voltage Detector, and Support For Multiple Images
2019-06-19 v2.0.1 Fix Button Delay
    No Longer Requires Rapid Press of Button
    [makerpoi_code.ino]
